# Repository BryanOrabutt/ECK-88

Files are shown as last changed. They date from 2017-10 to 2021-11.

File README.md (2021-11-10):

# ECK-88

This project is an attempt to recreate the Intel ECK-88 development kit using KiCAD software to recreate the board and schematics. There have been some additions to the board
to aid in both educational and demonstrational use. These new additions are outlined below:

 * Every address, data, and control signal is broken out to an IO header to allow for logic analyzer probing.
 * Every address, data, and most control signals are broken out to LEDs for use when single stepping.
 * A clock select was added that allows selection between the main 4 Mhz clock, an external clock, and a debounced push button
   for single stepping.
 * All GPIO lines are broken out to headers (rather than no connect from the original ECK-88)
 * All chips are socketed to allow replacement and reprogramming with ease.
 * DC Barrel jack and LM1084 linear regulator added to allow wide range of power inputs.

## Modification

If you wish to make any modifications to the current board, all of the files are designed in KiCAD. The KiCAD software can be obtained here: http://kicad.org/. All of the
custom symbols and footprints are found in the Libraries and Libraries.pretty folders and will need to be manually added to the KiCAD library search path. The board was
designed to meet the requirements of OSH Park's fabrication rules. For more information see: http://docs.oshpark.com/design-tools/kicad/

## License

This project is licensed under the MIT License - see the [LICENSE](LICENSE) file for details

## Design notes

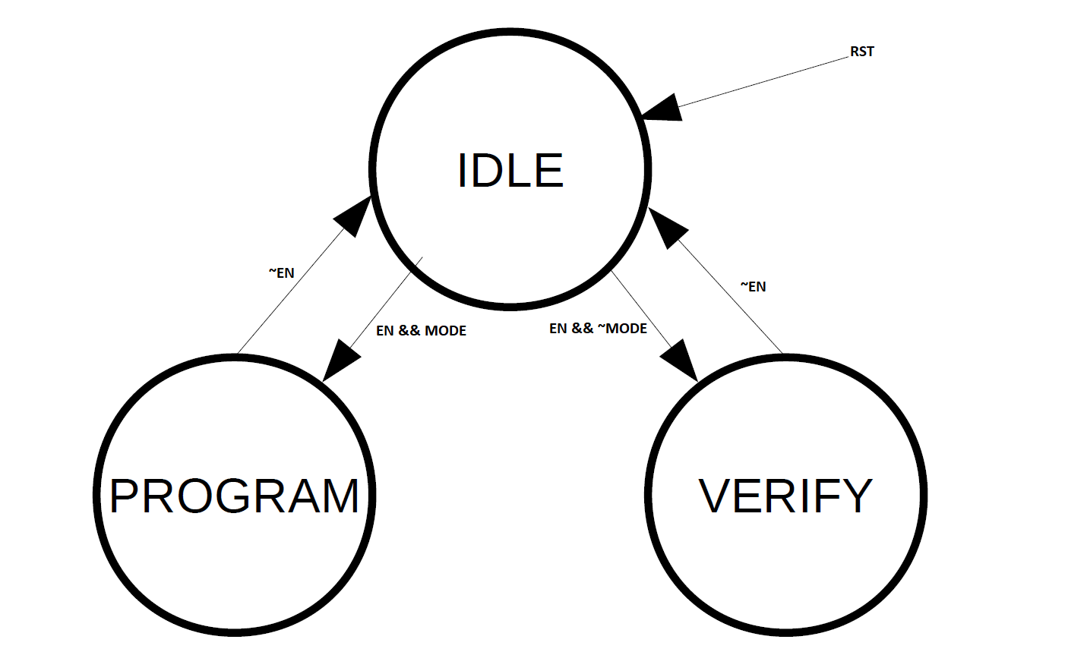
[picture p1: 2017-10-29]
PGM8755/state_machine.png

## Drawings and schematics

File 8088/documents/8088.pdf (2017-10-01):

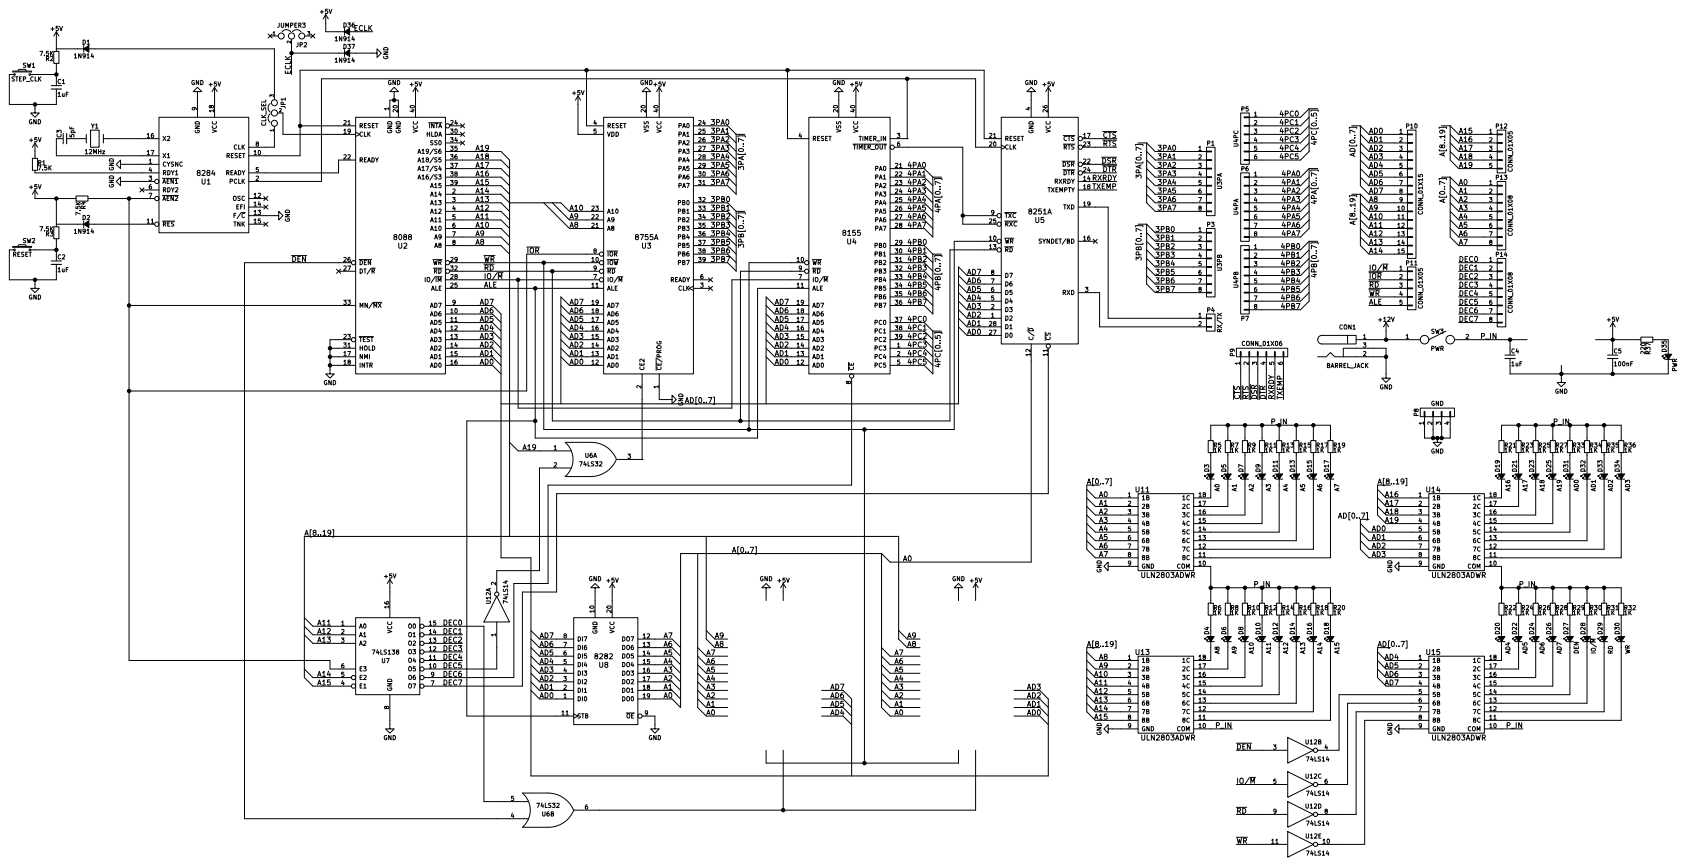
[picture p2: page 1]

9 RESET 10 RES 11 OSC 12 F/C 13 EFI 14 TNK 15 X2 16 X1 17 VCC 18 U1

1 A14 2 A13 3 A12 4 A11 5 A10 6 A9 7 A8 8 AD7 9 AD6 10 GND 20 HLDA VCC 30 40 AD5 11 RESET 21 HOLD 31 AD4 12 READY 22 RD 32 AD3 13 TEST 23 MN/MX 33 AD2 14

8 RD 9 WR 10 VSS 20 PB1 30 VCC 40 ALE 11 PA0 21 PB2 31 AD0 12 PA1 22 PB3 32 AD1 13 PA2 23 PB4 33 AD2 14 PA3 24 PB5 34 AD3 15 PA4 25 PB6 35 AD4 16 PA5 26 PB7 36 AD5 17 PA6 27 PC0 37 AD6 18 PA7 28 PC1 38 AD7 19 PB0 29 PC2 39 U4

4 D4 5 D5 6 D6 7 D7 8 TXC 9 WR 10 CLK 20 CS 11 RESET 21 C/D 12 DSR 22 RD 13 RTS 23 RXRDY 14 DTR 24 RXC 25 SYNDET/BD 16 VCC 26 CTS 17 D0 27 TXEMPTY 18 D1 28 TXD 19 U5

2 CLK 3 RESET 4 VDD 5 READY 6

6 P9 CONN_01X06 CTS RTS DSR DTR RXRDY TXEMP

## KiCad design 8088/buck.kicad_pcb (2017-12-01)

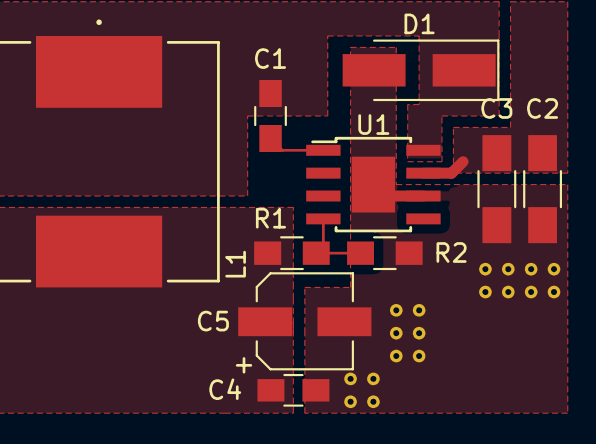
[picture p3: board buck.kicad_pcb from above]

Board: 2 copper layers, 10 parts (0 on the bottom side), 6 nets.

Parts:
C1: 10nF; C_0805_HandSoldering
C2, C3: 4.7uF; C_1206_HandSoldering
C4: 100nF; C_0805_HandSoldering
C5: 220uF; CP_Elec_5x5.3
D1: STPS5L60U; D_SMA_Handsoldering
L1: 22uH; SRR1208-220ML
R1: 30.9K±0.1%; R_0805_HandSoldering
R2: 10K±0.1%; R_0805_HandSoldering
U1: TPS5430; TI_SO-PowerPAD-8

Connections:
+5V: C4.1, C5.1, L1.2, R1.1
+BATT: C2.1, C3.1, U1.7
/PH: C1.2, D1.1, L1.1, U1.8
GND: C2.2, C3.2, C4.2, C5.2, D1.2, R2.2, U1.6, U1.9
unnamed: C1.1, U1.1
unnamed: R1.2, R2.1, U1.4

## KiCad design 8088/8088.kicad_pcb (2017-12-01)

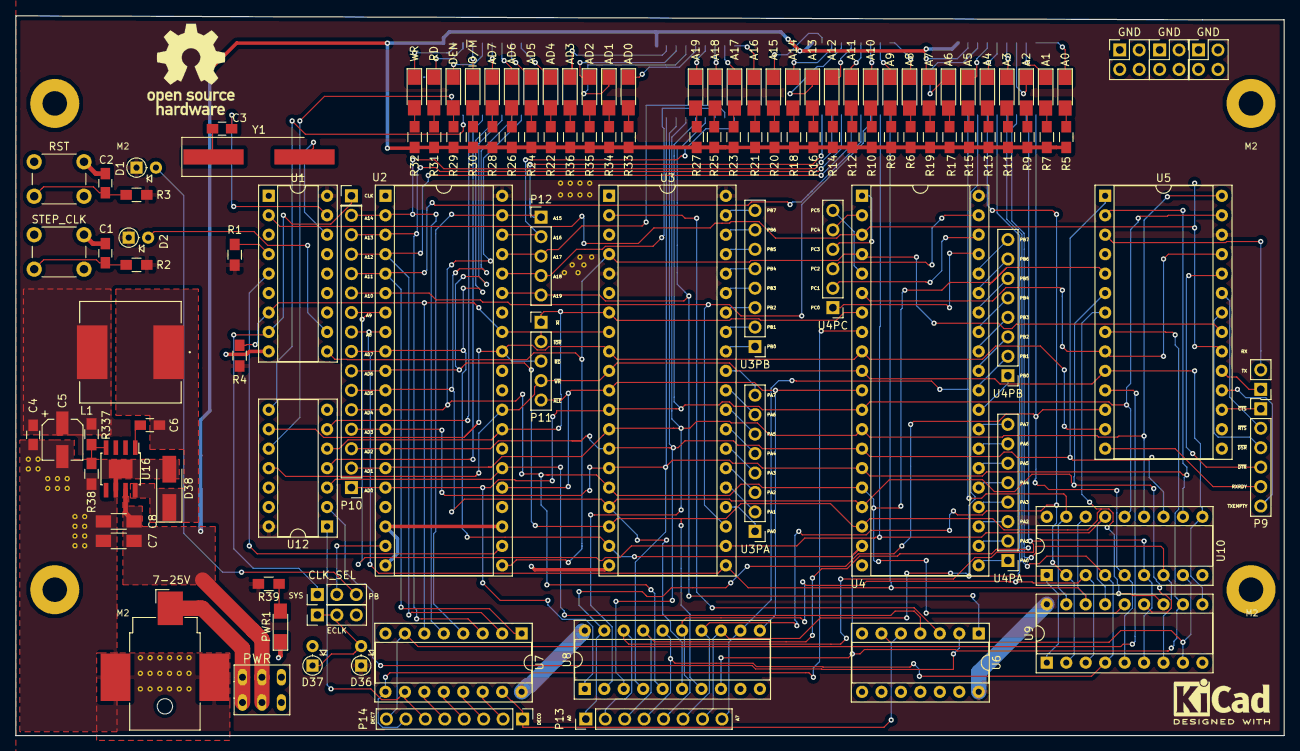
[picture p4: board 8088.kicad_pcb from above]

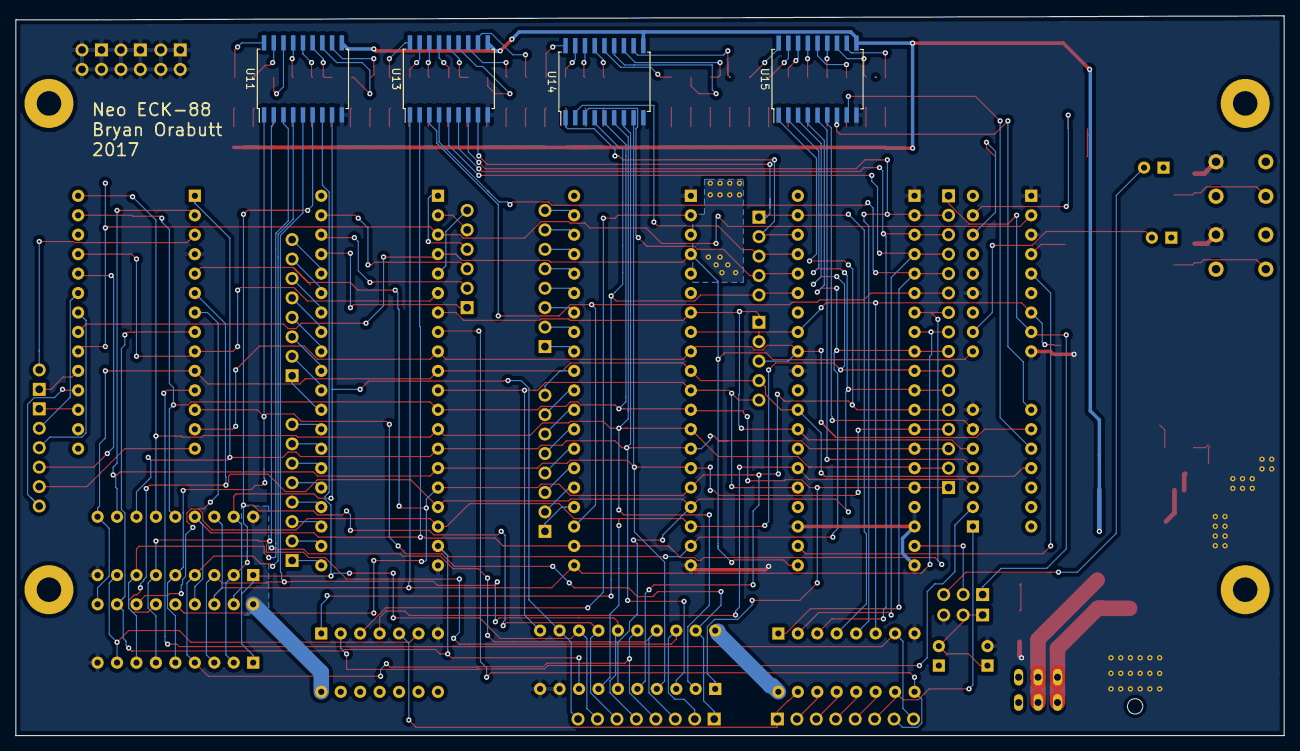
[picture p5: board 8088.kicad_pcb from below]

Board: 2 copper layers, 165.6 x 94.0 mm, 125 parts (4 on the bottom side), 182 nets.

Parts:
7-25V: BARREL_JACK; Barrel_Jack_CUI_PJ-036AH-SMT
A0: A0; LED_1206_HandSoldering
A1: A1; LED_1206_HandSoldering
A2: A2; LED_1206_HandSoldering
A3: A3; LED_1206_HandSoldering
A4: A4; LED_1206_HandSoldering
A5: A5; LED_1206_HandSoldering
A6: A6; LED_1206_HandSoldering
A7: A7; LED_1206_HandSoldering
A8: A8; LED_1206_HandSoldering
A9: A9; LED_1206_HandSoldering
A10: A10; LED_1206_HandSoldering
A11: A11; LED_1206_HandSoldering
A12: A12; LED_1206_HandSoldering
A13: A13; LED_1206_HandSoldering
A14: A14; LED_1206_HandSoldering
A15: A15; LED_1206_HandSoldering
A16: A16; LED_1206_HandSoldering
A17: A17; LED_1206_HandSoldering
A18: A18; LED_1206_HandSoldering
A19: A19; LED_1206_HandSoldering
AD0: AD0; LED_1206_HandSoldering
AD1: AD1; LED_1206_HandSoldering
AD2: AD2; LED_1206_HandSoldering
AD3: AD3; LED_1206_HandSoldering
AD4: AD4; LED_1206_HandSoldering
AD5: AD5; LED_1206_HandSoldering
AD6: AD6; LED_1206_HandSoldering
AD7: AD7; LED_1206_HandSoldering
C1, C2: 1uF; C_0805_HandSoldering
C3: 5pF; C_0805_HandSoldering
C4: 100nF; C_0805_HandSoldering
C5: 220uF; CP_Elec_5x5.3
C6: 10nF; C_0805_HandSoldering
C7, C8: 4.7uF; C_1206_HandSoldering
CLK: Pin_Header_Straight_1x01_Pitch2.54mm
CLK_SEL: CLK_SEL; Pin_Header_Straight_1x03_Pitch2.54mm
D1, D2, D36, D37: 1N914; D_DO-35_SOD27_P2.54mm_Vertical_AnodeUp
D38: STPS5L60U; D_SMA_Handsoldering
DEN: DEN; LED_1206_HandSoldering
GND: GND; Pin_Header_Straight_2x02_Pitch2.54mm
GND#2, GND#3: GND; Pin_Header_Straight_2x02_Pitch2.54mm
IO/~M: IO/~M; LED_1206_HandSoldering
JP2: JUMPER3; Pin_Header_Straight_1x03_Pitch2.54mm
L1: 22uH; SRR1208-220ML
P9: CONN_01X06; Pin_Header_Straight_1x06_Pitch2.54mm
P10: CONN_01X15; Pin_Header_Straight_1x15_Pitch2.54mm
P11, P12: CONN_01X05; Pin_Header_Straight_1x05_Pitch2.54mm
P13, P14: CONN_01X08; Pin_Header_Straight_1x08_Pitch2.54mm
PWR: PWR; SPST-SLIDE
PWR1: PWR; LED_1206_HandSoldering
R1, R2, R3, R4, R39: 7.5K; R_0805_HandSoldering
R5, R6, R7, R8, R9, R10, R11, R12, R13, R14, R15, R16, R17, R18, R19, R20, R21, R22, R23, R24, R25, R26, R27, R28, R29, R30, R31, R32, R33, R34, R35, R36: 1K; R_0805_HandSoldering
R38: 10K±0.1%; R_0805_HandSoldering
R337: 30.9K±0.1%; R_0805_HandSoldering
RD: RD; LED_1206_HandSoldering
RST: RESET; SW_PUSH_6mm_h5mm
RX/TX: RX/TX; Pin_Header_Straight_1x02_Pitch2.54mm
STEP_CLK: STEP_CLK; SW_PUSH_6mm_h5mm
U1: 8284; DIP-18_W7.62mm_Socket
U2: 8088; DIP-40_W15.24mm_Socket
U3: 8755A; DIP-40_W15.24mm_Socket
U3PA: U3PA; Pin_Header_Straight_1x08_Pitch2.54mm
U3PB: U3PB; Pin_Header_Straight_1x08_Pitch2.54mm
U4: 8155; DIP-40_W15.24mm_Socket
U4PA: U4PA; Pin_Header_Straight_1x08_Pitch2.54mm
U4PB: U4PB; Pin_Header_Straight_1x08_Pitch2.54mm
U4PC: U4PC; Pin_Header_Straight_1x06_Pitch2.54mm
U5: 8251A; DIP-28_W15.24mm_Socket
U6: 74LS32; DIP-14_W7.62mm_Socket
U7: 74LS138; DIP-16_W7.62mm_Socket
U8: 8282; DIP-20_W7.62mm_Socket
U9, U10: 2114; DIP-18_W7.62mm_Socket
U11, U13, U14, U15: ULN2803ADWR; SOIC-18W_7.5x11.6mm_Pitch1.27mm
U12: 74LS14; DIP-14_W7.62mm_Socket
U16: TPS5430; TI_SO-PowerPAD-8
WR: WR; LED_1206_HandSoldering
Y1: 12MHz; Crystal_SMD_HC49-SD_HandSoldering

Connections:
+5V: C4.1, C5.1, D1.1, D2.1, D36.1, L1.2, R1.1, R2.2, R3.2, R4.2, R39.2, R337.1, U1.18, U2.40, U3.5, U3.40, U4.40, U5.26, U6.14, U7.16, U8.20, U9.18, U10.18, U12.14
+12V: 7-25V.1, PWR.1, PWR.6
/3PA0: U3.24, U3PA.1
/3PA1: U3.25, U3PA.2
/3PA2: U3.26, U3PA.3
/3PA3: U3.27, U3PA.4
/3PA4: U3.28, U3PA.5
/3PA5: U3.29, U3PA.6
/3PA6: U3.30, U3PA.7
/3PA7: U3.31, U3PA.8
/3PB0: U3.32, U3PB.1
/3PB1: U3.33, U3PB.2
/3PB2: U3.34, U3PB.3
/3PB3: U3.35, U3PB.4
/3PB4: U3.36, U3PB.5
/3PB5: U3.37, U3PB.6
/3PB6: U3.38, U3PB.7
/3PB7: U3.39, U3PB.8
/4PA0: U4.21, U4PA.1
/4PA1: U4.22, U4PA.2
/4PA2: U4.23, U4PA.3
/4PA3: U4.24, U4PA.4
/4PA4: U4.25, U4PA.5
/4PA5: U4.26, U4PA.6
/4PA6: U4.27, U4PA.7
/4PA7: U4.28, U4PA.8
/4PB0: U4.29, U4PB.1
/4PB1: U4.30, U4PB.2
/4PB2: U4.31, U4PB.3
/4PB3: U4.32, U4PB.4
/4PB4: U4.33, U4PB.5
/4PB5: U4.34, U4PB.6
/4PB6: U4.35, U4PB.7
/4PB7: U4.36, U4PB.8
/4PC0: U4.37, U4PC.1
/4PC1: U4.38, U4PC.2
/4PC2: U4.39, U4PC.3
/4PC3: U4.1, U4PC.4
/4PC4: U4.2, U4PC.5
/4PC5: U4.5, U4PC.6
/A0: P13.1, U5.12, U8.19, U9.5, U10.5, U11.1
/A1: P13.2, U8.18, U9.6, U10.6, U11.2
/A2: P13.3, U8.17, U9.7, U10.7, U11.3
/A3: P13.4, U8.16, U9.4, U10.4, U11.4
/A4: P13.5, U8.15, U9.3, U10.3, U11.5
/A5: P13.6, U8.14, U9.2, U10.2, U11.6
/A6: P13.7, U8.13, U9.1, U10.1, U11.7
/A7: P13.8, U8.12, U9.17, U10.17, U11.8
/A8: P10.9, U2.8, U3.21, U9.16, U10.16, U13.1
/A9: P10.10, U2.7, U3.22, U9.15, U10.15, U13.2
/A10: P10.11, U2.6, U3.23, U13.3
/A11: P10.12, U2.5, U7.1, U13.4
/A12: P10.13, U2.4, U7.2, U13.5
/A13: P10.14, U2.3, U7.3, U13.6
/A14: P10.15, U2.2, U7.5, U13.7
/A15: P12.1, U2.39, U7.4, U13.8
/A16: P12.2, U2.38, U14.1
/A17: P12.3, U2.37, U14.2
/A18: P12.4, U2.36, U14.3
/A19: P12.5, U2.35, U6.1, U14.4
/AD0: P10.1, U2.16, U3.12, U4.12, U5.27, U8.1, U10.14, U14.5
/AD1: P10.2, U2.15, U3.13, U4.13, U5.28, U8.2, U10.13, U14.6
/AD2: P10.3, U2.14, U3.14, U4.14, U5.1, U8.3, U10.12, U14.7
/AD3: P10.4, U2.13, U3.15, U4.15, U5.2, U8.4, U10.11, U14.8
/AD4: P10.5, U2.12, U3.16, U4.16, U5.5, U8.5, U9.14, U15.1
/AD5: P10.6, U2.11, U3.17, U4.17, U5.6, U8.6, U9.13, U15.2
/AD6: P10.7, U2.10, U3.18, U4.18, U5.7, U8.7, U9.12, U15.3
/AD7: P10.8, U2.9, U3.19, U4.19, U5.8, U8.8, U9.11, U15.4
/ALE: P11.5, U2.25, U3.11, U4.11, U8.11
/Buck Converter/PH: C6.2, D38.1, L1.1, U16.8
/DEC0: P14.1, U6.5, U7.15
/DEC1: P14.2, U7.14
/DEC2: P14.3, U7.13
/DEC3: P14.4, U7.12
/DEC4: P14.5, U7.11
/DEC5: P14.6, U7.10, U12.1
/DEC6: P14.7, U4.8, U7.9
/DEC7: P14.8, U5.11, U7.7
/ECLK: D36.2, D37.1, JP2.1, JP2.2
/IO/~M: P11.1, U2.28, U3.7, U4.7, U12.5
/RXRDY: P9.5, U5.14
/TXEMP: P9.6, U5.18
/~CTS: P9.1, U5.17
/~DEN: U2.26, U6.4, U12.3
/~DSR: P9.3, U5.22
/~DTR: P9.4, U5.24
/~IOR: P11.2, R4.1, U1.7, U2.33, U3.8, U7.6
/~RD: P11.3, U2.32, U3.9, U4.9, U5.13, U12.9
/~RTS: P9.2, U5.23
/~WR: P11.4, U2.29, U3.10, U4.10, U5.10, U9.10, U10.10, U12.11
GND: 7-25V.2, 7-25V.3, C1.2, C2.2, C4.2, C5.2, C7.2, C8.2, D37.2, D38.2, GND.1, GND.2, GND.3, GND.4, GND#2.1, GND#2.2, GND#2.3, GND#2.4, GND#3.1, GND#3.2, GND#3.3, GND#3.4, JP2.3, PWR1.1, R38.2, RST.1, STEP_CLK.1, U1.1, U1.3, U1.9, U1.13, U2.1, U2.17, U2.18, U2.20, U2.23, U2.31, U3.1, U3.20, U4.20, U5.4, U6.7, U7.8, U8.9, U8.10, U9.9, U10.9, U11.9, U12.7, U13.9, U14.9, U15.9, U16.6, U16.9
unnamed: C1.1, R2.1, STEP_CLK.2
unnamed: C2.1, R3.1, RST.2
unnamed: C3.1, U1.17
unnamed: C3.2, Y1.1
unnamed: C6.1, U16.1
unnamed: CLK_SEL.3, D1.2
unnamed: D2.2, U1.11
unnamed: A0.1, U11.18
unnamed: A0.2, R5.2
unnamed: A8.1, U13.18
unnamed: A8.2, R6.2
unnamed: A1.1, U11.17
unnamed: A1.2, R7.2
unnamed: A9.1, U13.17
unnamed: A9.2, R8.2
unnamed: A2.1, U11.16
unnamed: A2.2, R9.2
unnamed: A10.1, U13.16
unnamed: A10.2, R10.2
unnamed: A3.1, U11.15
unnamed: A3.2, R11.2
unnamed: A11.1, U13.15
unnamed: A11.2, R12.2
unnamed: A4.1, U11.14
unnamed: A4.2, R13.2
unnamed: A12.1, U13.14
unnamed: A12.2, R14.2
unnamed: A5.1, U11.13
unnamed: A5.2, R15.2
unnamed: A13.1, U13.13
unnamed: A13.2, R16.2
unnamed: A6.1, U11.12
unnamed: A6.2, R17.2
unnamed: A14.1, U13.12
unnamed: A14.2, R18.2
unnamed: A7.1, U11.11
unnamed: A7.2, R19.2
unnamed: A15.1, U13.11
unnamed: A15.2, R20.2
unnamed: A16.1, U14.18
unnamed: A16.2, R21.2
unnamed: AD4.1, U15.18
unnamed: AD4.2, R22.2
unnamed: A17.1, U14.17
unnamed: A17.2, R23.2
unnamed: AD5.1, U15.17
unnamed: AD5.2, R24.2
unnamed: A18.1, U14.16
unnamed: A18.2, R25.2
unnamed: AD6.1, U15.16
unnamed: AD6.2, R26.2
unnamed: A19.1, U14.15
unnamed: A19.2, R27.2
unnamed: AD7.1, U15.15
unnamed: AD7.2, R28.2
unnamed: DEN.1, U15.14
unnamed: DEN.2, R29.2
unnamed: IO/~M.1, U15.13
unnamed: IO/~M.2, R30.2
unnamed: RD.1, U15.12
unnamed: R31.2, RD.2
unnamed: U15.11, WR.1
unnamed: R32.2, WR.2
unnamed: AD0.1, U14.14
unnamed: AD0.2, R33.2
unnamed: AD1.1, U14.13
unnamed: AD1.2, R34.2
unnamed: AD2.1, U14.12
unnamed: AD2.2, R35.2
unnamed: AD3.1, U14.11
unnamed: AD3.2, R36.2
unnamed: CLK.1, CLK_SEL.1, U1.8
unnamed: CLK_SEL.2, U2.19
unnamed: RX/TX.1, U5.19
unnamed: RX/TX.2, U5.3
unnamed: PWR1.2, R39.1
unnamed: R1.2, U1.4
unnamed: R38.1, R337.2, U16.4
unnamed: U1.2, U4.3, U5.20
unnamed: U1.5, U2.22
unnamed: U1.10, U2.21, U3.4, U4.4, U5.21
unnamed: U1.16, Y1.2
unnamed: U3.2, U6.3
unnamed: U4.6, U5.9, U5.25
unnamed: U6.6, U9.8, U10.8
unnamed: U6.2, U12.2
unnamed: U12.4, U15.5
unnamed: U12.6, U15.6
unnamed: U12.8, U15.7
unnamed: U12.10, U15.8
P_IN: C7.1, C8.1, PWR.2, PWR.5, R5.1, R6.1, R7.1, R8.1, R9.1, R10.1, R11.1, R12.1, R13.1, R14.1, R15.1, R16.1, R17.1, R18.1, R19.1, R20.1, R21.1, R22.1, R23.1, R24.1, R25.1, R26.1, R27.1, R28.1, R29.1, R30.1, R31.1, R32.1, R33.1, R34.1, R35.1, R36.1, U11.10, U13.10, U14.10, U15.10, U16.7

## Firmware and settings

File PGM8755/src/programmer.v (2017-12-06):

`timescale 1ns / 1ps
//////////////////////////////////////////////////////////////////////////////////
// Engineer: Bryan Orabutt
// 
// Create Date:    	00:07:41 10/27/2017 
// Design Name: 	PGM8755
// Module Name:    	programmer
// Project Name:   	PGM8755
// Target Devices: 	Spartan 3E Starter Board, Mojo board (Spartan 6 xc6slx9-2tqg144)
// Description:  	Module to perform 8755 EPROM programming and verification
//////////////////////////////////////////////////////////////////////////////////
module programmer(input clk, rst, mode, en, tx_busy, input [7:0] data_in, output reg tx_block, rdy, 
				  ale, data_latch, ce, rd, output reg[10:0] addr_dat);
				  
	localparam PROGRAM = 2'b01, VERIFY = 2'b10, IDLE = 2'b00;

	reg[1:0] state; //state machine state (PROGRAM, IDLE, or VERIFY)
	reg[10:0] address; //intenrnal address assigned to adr_dat during ALE phase
	wire delay_rdy; //output of counter, determines when it's okay to move from data to ALE phase.
	wire ale_rdy; //output of counter, allows ALE to meet setup/hold times
	wire rd_wr_rdy; //output of counter, allows ~RD/WR wire to meet setup/hold times.
	wire prg_end; //allows settling time for data_latch
	
	/* start: starts the counter during the data phase.
	*  addr_state: indicates ALE phase (1) or data phase (0) during PROGRAM.
	*  tx_state: indicates ALE phase (0) or rd phase (1) during VERIFY.
	*/
	reg start, addr_state, tx_state, prg_fall;
	
	/* Counter will output 1 to delay_rdy after 50.002 ms. Output valid for 1 cycle (20 ns) */
	delay_cycles #(.WAIT_CYCLES(1000100)) prg_dly(.clk(clk), .rst(rst), .rdy(delay_rdy), .en(start));
	
	/* Counter will output 1 to ale_rdy after 60 ns. Output valid for 1 cycle (20 ns) */
	delay_cycles #(.WAIT_CYCLES(3)) ale_dly(.clk(clk), .rst(rst), .rdy(ale_rdy), .en(ale));	
	
	/* Counter will output 1 to ale_rdy after 2 us. Output valid for 1 cycle (20 ns) */
	delay_cycles #(.WAIT_CYCLES(100)) prg_fall_dly(.clk(clk), .rst(rst), .rdy(prg_end), .en(rd));
	
	/* Evaluate state machine every cycle */
	always@(posedge clk)begin
		if(rst) begin
			rdy <= 1'b0;
			data_latch <= 1'b1;
			addr_dat <= 11'b0;
			state <= IDLE;
			addr_state <= 1'b0;
			addr_state <= 1'b1;
			address <= 11'hFF0; //8088 resets to FFFF0
			rd <= 1'b1;
			tx_state <= 0;
			prg_fall <= 0;
		end
		else begin
			/* IDLE && ~en should stay in IDLE state */
			if(state == IDLE && ~en) begin
				start <= 0;
				rdy <= 0;
				addr_dat <= 11'b0;
				data_latch <= 0;
			end
			/* If en is high, check mode to see if we are programming or verifying */
			else if(state == IDLE && en) state <= (mode) ? PROGRAM:VERIFY;
			/* If we are programming begin programming routine */
			else if(state == PROGRAM && en) begin
				/* Check if we need to latch address or latch data */
				if(addr_state) begin //latch address
					ce <= 1'b0;
					addr_dat <= address; //put address on the bus
					ale <= 1; //ALE is high active
					if(ale_rdy) begin
						addr_state <= 1'b0; //change to data phase.
						data_latch <= 1'b1; //data_latch is low active.
						ale <= 0; //end address latch
					end
				end
				else begin
					start <= 1'b1; //hold start high during whole data phase
					rd <= 1'b1; //rd is low active. 
					if(~delay_rdy) begin //counter has not finished
						ce <= 1'b1; //hold ce/prog in the prog state
						addr_dat[7:0] <= data_in; //put data on the bus
						//ale <= 1'b0; //make sure ALE is not active
						data_latch <= 1'b0; //keep data latch on until counter is done
						prg_fall <= 1'b1;
					end
					else begin
						if(prg_end) begin
							addr_state <= 1'b1; //change to ALE phase
							address <= address - 1'b1; //decrement address
							start <= 1'b0; //stop counter
							prg_fall <= 1'b0;
						end
					end
				end
			end
			/* If we are verifying, begin verify routine */
			else if(state == VERIFY && en) begin
				ce <= 1'b0; //remain in ce state for whole verify phase
				if(~tx_state && ~tx_busy) begin //we are in ALE state
					rdy <= 1'b0; //not ready to transmit data
					ale <= 1'b1; //latch address
					addr_dat <= address; //put address on bus
					tx_state <= 1'b1; //change to read phase
					rd <= 1'b1;
					tx_block <= 1'b1; //do not transmit while latching address.
				end
				else begin //we are in RD phase
					tx_block <= 1'b0;
					rd <= 1'b0; //rd is low active
					rdy <= 1'b1; //we are ready to transmit data.
				end
			end
			else state <= IDLE;
		end
	end

endmodule

module delay_cycles(input clk, rst, en, output rdy);
	parameter WAIT_CYCLES = 1000000;
	parameter CTR_SIZE = $clog2(WAIT_CYCLES);
	
	reg[CTR_SIZE-1:0] counter;
	
	always@(posedge clk) begin
		if(rst || ~en) counter <= 0;
		else counter <= counter + 1'b1;
	end
	
	assign rdy = counter == WAIT_CYCLES;
	
endmodule

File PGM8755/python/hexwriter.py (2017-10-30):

#!/usr/bin/env python3

import serial, sys, getopt

usage = '''\nhexwriter [OPTION] -f FILE\nDefault operation is to use 115200 baud on /dev/ttyUSB0\nOPTIONS:\n-h displays usage\n-b baud rate\n-d device handle\n-f file name'''

try:
	opts, args = getopt.getopt(sys.argv[1:], 'b:d:f:h', ['baud=', 'device=', 'file=', 'help'])
	
except getopt.GetoptError:
	print(usage)
	sys.exit(2)

baud_rate = 115200
dev = '/dev/ttyUSB0'
filename = ''

for opt, arg in opts:
	if opt in ('-h', '--help'):
		print(usage)
		sys.exit(2)
	elif opt in ('-b', '--baud'):
		baud_rate = arg
	elif opt in ('-d', '--device'):
		dev = arg
	elif opt in ('-f', '--file'):
		filename = arg
	else:
		print(usage)
		sys.exit(2)

if filename == '':
	raise Exception("No file given\n%s" % (usage))
	sys.exit(2)

ser = serial.Serial()
ser.baudrate = baud_rate
ser.port = dev

try:
	ser.open()
except SerialException:
	print('Could not open device: %s' % (dev))
	sys.exit(2)

try:
	f = open(filename, 'rb')
except IOError:
	print("Could not read file: %s" % (filename))
	sys.exit(2)

with f:
	byte = f.read(1)
	while byte != b"":
		ser.write(byte)
		byte = f.read(1)

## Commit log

2017-09-24 Fixed schematic errors and added custom component footprints for the switches/PBs
    [8088.sch]
2017-09-24 Started PCB
    [8088.kicad_pcb, 8088.sch]
2017-09-26 Initial PCB design finished
    [8088.kicad_pcb, 8088.sch]
2017-09-26 forgot to add PCB file, oops!
    [8088.kicad_pcb]
2017-09-26 Added PCB images
    [8088.kicad_pcb]
2017-09-27 Fixed pin number discrepency
2017-09-27 Fixed schematic error
    [8088.sch]
2017-09-27 Fixed pin 26 discrepency on PCB layout
    [8088.kicad_pcb]
2017-09-27 Fixed PCB routing issue
    [8088.kicad_pcb]
2017-09-30 Adding IO headers to schematic
    [8088.sch]
2017-09-30 Updated libraries. Added IO headers to schematics. TODO: Route ISA bus
    [8088.kicad_pcb, 8088.sch]
2017-10-01 Second board revision down. Added bling :)
    [8088.kicad_pcb, 8088.sch]
2017-10-01 Added gerbers.
    [8088-B.Adhes.gbr, 8088-B.Cu.gbl, 8088-B.Cu.gbr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]
2017-10-01 Forgot to add footprint library that was used
2017-10-10 Fixed chip socket widths
    [8088.sch]
2017-10-10 Reformatted README
    [8088.kicad_pcb]
2017-10-13 Changed regulator
    [8088.kicad_pcb, 8088.sch]
2017-10-13 Updated board layout
    [8088.kicad_pcb]
2017-10-13 Fixed symbol issue
    [8088.sch]
2017-10-13 Generated gerbers.
    [8088-B.Adhes.gbr, 8088-B.Cu.gbl, 8088-B.Cu.gbr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]
2017-10-19 Updated PCB to use top side power plane
    [8088.kicad_pcb, 8088.sch]
2017-10-19 Fixed some track routing
    [8088.kicad_pcb]
2017-10-21 Board revised based on prototype
    [8088.kicad_pcb, 8088.sch]
2017-10-21 Fixed some silkscreen issues
    [8088.kicad_pcb]
2017-10-23 Fixed issue with ECLK
    [8088.kicad_pcb, 8088.sch]
2017-10-27 Started FPGA programmer for 8755A
    [mojo_top_pad.csv]
2017-10-27 fixed logic issue with programmer.
    [programmer.v]
2017-10-29 Removed ignored files
    [mojo_top_pad.csv]
2017-12-01 Board rev2 done. Added buck converter circuit
    [8088-B.Cu.gbl, 8088-B.Fab.gbr, 8088-B.Mask.gbs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]
2021-11-09 Update README.md
    https://forum.kicad.info/t/warning-avoid-all-links-to-kicad-pcb-org-use-kicad-org/31521

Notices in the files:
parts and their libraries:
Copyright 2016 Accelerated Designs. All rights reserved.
